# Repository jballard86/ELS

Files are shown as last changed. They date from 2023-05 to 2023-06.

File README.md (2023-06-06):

# Electronic Lead Screw
    By Jeff Ballard

Anticipated features:
  - Metric / Inch threading
  - Metric / Inch feeding
  - Auto threading with 2 steppers
  - Auto turn to a specified diameter
  - Pendent Control with:
    - Manual Z control
    - Manual X control
  - Radius cutting
  - Ball cutting
  - chamfer cutting
  - Digital Dial replacements (pipe dream)

This Lead Screw is 100% untested at this point, the code works on a test stand that has the following:
  - 24v power supply
  - 12v power supply
  - Custom PCB w/ a Teensy 4.0
  - 1 stepper motor w/Driver
  - 1 DC motor w/encoder
  - various display/interface hardware

PCB is 100% operational on test board.  Cad files to come for mounting all components in a housing for mounting near the lathe.

Lathe installation will happen shortly.

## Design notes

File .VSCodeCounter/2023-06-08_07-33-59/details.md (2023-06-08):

# Details

Date : 2023-06-08 07:33:59

Directory f:\\OneDrive\\Documents\\PlatformIO\\Projects\\ELS\\src

Total : 10 files,  1261 codes, 176 comments, 125 blanks, all 1562 lines

[Summary](results.md) / Details / [Diff Summary](diff.md) / [Diff Details](diff-details.md)

## Files
| filename | language | code | comment | blank | total |
| :--- | :--- | ---: | ---: | ---: | ---: |
| [src/Auto_Radius.h](/src/Auto_Radius.h) | C++ | 104 | 40 | 16 | 160 |
| [src/Chamfer.h](/src/Chamfer.h) | C++ | 2 | 0 | 1 | 3 |
| [src/Display.h](/src/Display.h) | C++ | 82 | 5 | 21 | 108 |
| [src/Feed.h](/src/Feed.h) | C++ | 17 | 1 | 7 | 25 |
| [src/Interface.h](/src/Interface.h) | C++ | 584 | 44 | 24 | 652 |
| [src/Interrupts.h](/src/Interrupts.h) | C++ | 21 | 3 | 7 | 31 |
| [src/Main.cpp](/src/Main.cpp) | C++ | 71 | 28 | 15 | 114 |
| [src/Menu.h](/src/Menu.h) | C++ | 351 | 12 | 24 | 387 |
| [src/Things_to_do.h](/src/Things_to_do.h) | C++ | 0 | 24 | 1 | 25 |
| [src/Thread.h](/src/Thread.h) | C++ | 29 | 19 | 9 | 57 |

[Summary](results.md) / Details / [Diff Summary](diff.md) / [Diff Details](diff-details.md)

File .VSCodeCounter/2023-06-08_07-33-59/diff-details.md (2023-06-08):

# Diff Details

Date : 2023-06-08 07:33:59

Directory f:\\OneDrive\\Documents\\PlatformIO\\Projects\\ELS\\src

Total : 6 files,  -13 codes, 17 comments, -3 blanks, all 1 lines

[Summary](results.md) / [Details](details.md) / [Diff Summary](diff.md) / Diff Details

## Files
| filename | language | code | comment | blank | total |
| :--- | :--- | ---: | ---: | ---: | ---: |
| [src/Auto_Radius.h](/src/Auto_Radius.h) | C++ | -4 | 11 | -1 | 6 |
| [src/Display.h](/src/Display.h) | C++ | 0 | 3 | 0 | 3 |
| [src/Feed.h](/src/Feed.h) | C++ | -4 | 0 | 0 | -4 |
| [src/Main.cpp](/src/Main.cpp) | C++ | -2 | 2 | -3 | -3 |
| [src/Things_to_do.h](/src/Things_to_do.h) | C++ | 0 | 1 | 0 | 1 |
| [src/Thread.h](/src/Thread.h) | C++ | -3 | 0 | 1 | -2 |

[Summary](results.md) / [Details](details.md) / [Diff Summary](diff.md) / Diff Details

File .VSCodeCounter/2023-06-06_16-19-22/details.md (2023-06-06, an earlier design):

# Details

Date : 2023-06-06 16:19:22

Directory f:\\OneDrive\\Documents\\PlatformIO\\Projects\\ELS\\src

Total : 9 files,  1148 codes, 146 comments, 116 blanks, all 1410 lines

[Summary](results.md) / Details / [Diff Summary](diff.md) / [Diff Details](diff-details.md)

## Files
| filename | language | code | comment | blank | total |
| :--- | :--- | ---: | ---: | ---: | ---: |
| [src/Auto_Radius.h](/src/Auto_Radius.h) | C++ | 21 | 27 | 8 | 56 |
| [src/Display.h](/src/Display.h) | C++ | 82 | 2 | 21 | 105 |
| [src/Feed.h](/src/Feed.h) | C++ | 21 | 1 | 7 | 29 |
| [src/Interface.h](/src/Interface.h) | C++ | 554 | 43 | 23 | 620 |
| [src/Interrupts.h](/src/Interrupts.h) | C++ | 21 | 3 | 7 | 31 |
| [src/Main.cpp](/src/Main.cpp) | C++ | 69 | 19 | 18 | 106 |
| [src/Menu.h](/src/Menu.h) | C++ | 348 | 14 | 23 | 385 |
| [src/Things_to_do.h](/src/Things_to_do.h) | C++ | 0 | 18 | 1 | 19 |
| [src/Thread.h](/src/Thread.h) | C++ | 32 | 19 | 8 | 59 |

[Summary](results.md) / Details / [Diff Summary](diff.md) / [Diff Details](diff-details.md)

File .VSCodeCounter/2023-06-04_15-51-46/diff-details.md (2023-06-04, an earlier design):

# Diff Details

Date : 2023-06-04 15:51:46

Directory f:\\OneDrive\\Documents\\PlatformIO\\Projects\\ELS\\src

Total : 6 files,  13 codes, 5 comments, -3 blanks, all 15 lines

[Summary](results.md) / [Details](details.md) / [Diff Summary](diff.md) / Diff Details

## Files
| filename | language | code | comment | blank | total |
| :--- | :--- | ---: | ---: | ---: | ---: |
| [src/Display.h](/src/Display.h) | C++ | 6 | 1 | 4 | 11 |
| [src/Feed.h](/src/Feed.h) | C++ | 1 | -1 | -2 | -2 |
| [src/Interface.h](/src/Interface.h) | C++ | 4 | 0 | -1 | 3 |
| [src/Main.cpp](/src/Main.cpp) | C++ | 1 | 4 | -3 | 2 |
| [src/Things_to_do.h](/src/Things_to_do.h) | C++ | 0 | 3 | 0 | 3 |
| [src/Thread.h](/src/Thread.h) | C++ | 1 | -2 | -1 | -2 |

[Summary](results.md) / [Details](details.md) / [Diff Summary](diff.md) / Diff Details

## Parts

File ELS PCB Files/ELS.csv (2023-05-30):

# | Reference | Qty | Value | Footprint | DNP
1 | C1 | 1 | CL31B106KBHNNNE | ELS:CAPC3216X140N
2 | C2 | 1 | CL32B226MOJNNNECAP_CL32_SAM-M | ELS:CAP_CL32_SAM-M
3 | ENCODER0, POWER_INPUT0, STEPPER1, STEPPER2 | 4 | 1-2834015-4 | ELS:TE_1-2834015-4
4 | J1, J2, J3, J4, J5 | 5 | B4B-PH-K-S_LF__SN_ | SamacSys_Parts:SHDR4W50P0X200_1X4_990X450X600P
5 | PS1 | 1 | P78E05-1000 | ELS:CONV_P78E05-1000
6 | Q1, Q2, Q3, Q4, Q5, Q6 | 6 | MMBT2222ALT3G | SamacSys_Parts:SOT96P237X111-3N
7 | R1, R6, R9, R12, R15, R18 | 6 | CRCW12061K00FKEAC | ELS:RESC3216X60N
8 | R2, R7, R10, R13, R16, R19 | 6 | CR1206-FX-8250ELF | ELS:RESC3216X75N
9 | R5, R8, R11, R14, R17, R20 | 6 | CRCW1206220RFKEAC | ELS:RESC3216X60N
10 | R23, R24, R25, R26 | 4 | CRCW12064K70FKEBC | SamacSys_Parts:RESC3216X60N
11 | TEENSY_4.0 | 1 | TEENSY_4.0 | ELS:TEENSY_4.0

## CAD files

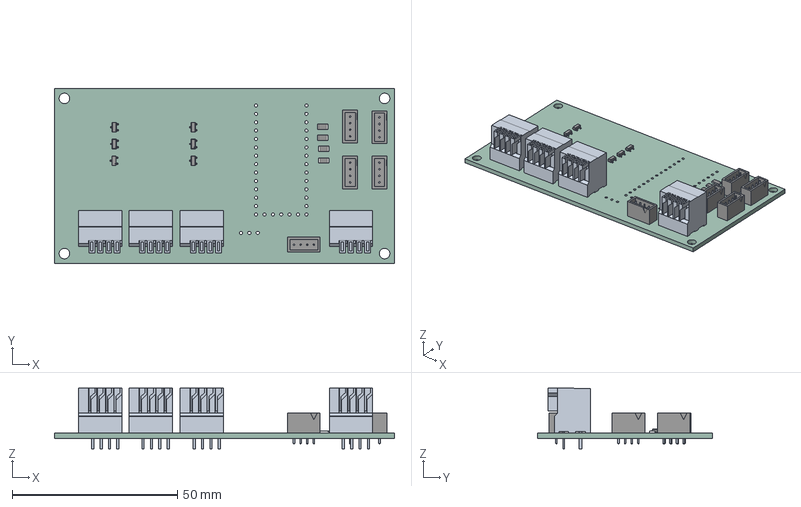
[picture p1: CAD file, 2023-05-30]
ELS PCB Files/ELS.step
103.0 x 53.0 x 18.5 mm
ELS PCB

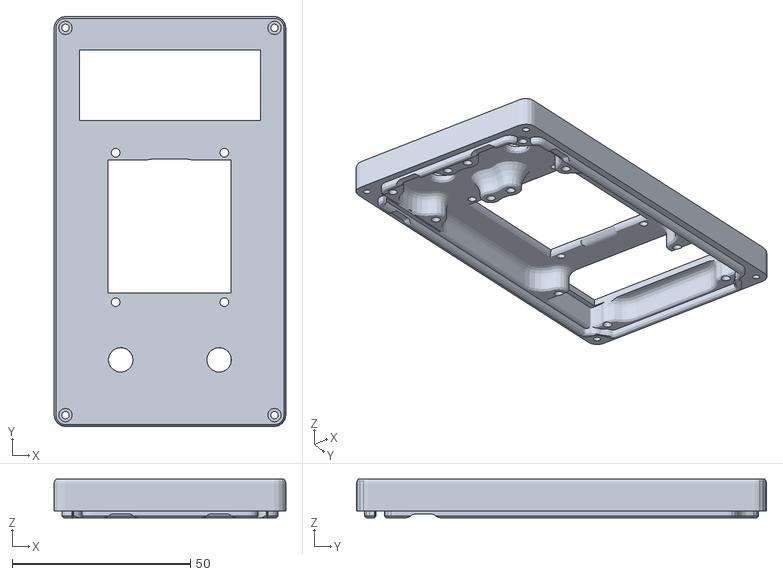
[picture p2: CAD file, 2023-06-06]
ELS STL Files/Housing Top r3.stl
65.0 x 115.0 x 10.9

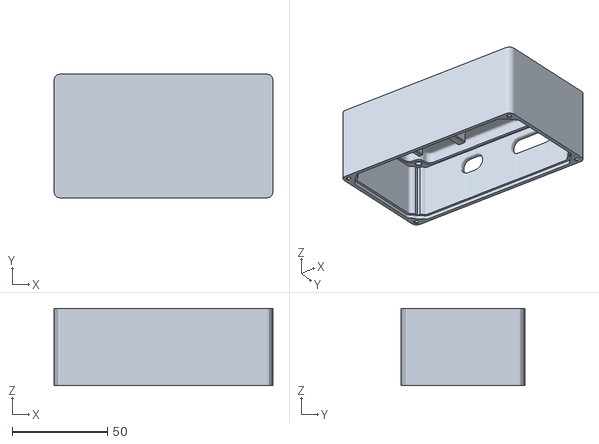
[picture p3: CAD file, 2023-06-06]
ELS STL Files/Housing Bottom r2.stl
115.0 x 65.0 x 40.6

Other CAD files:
ELS PCB Files/1-2834015-4.iam
ELS PCB Files/B4B-PH-K-S_LF__SN_.iam
ELS PCB Files/COMPOUND.ipt
ELS PCB Files/COMPOUND_1.ipt
ELS PCB Files/CRCW12064K70FKEBC.iam
ELS PCB Files/ELS PCB.ipt
ELS PCB Files/MMBT2222ALT3G.iam
ELS PCB Files/SOLID.ipt
ELS PCB Files/SOLID_1.ipt

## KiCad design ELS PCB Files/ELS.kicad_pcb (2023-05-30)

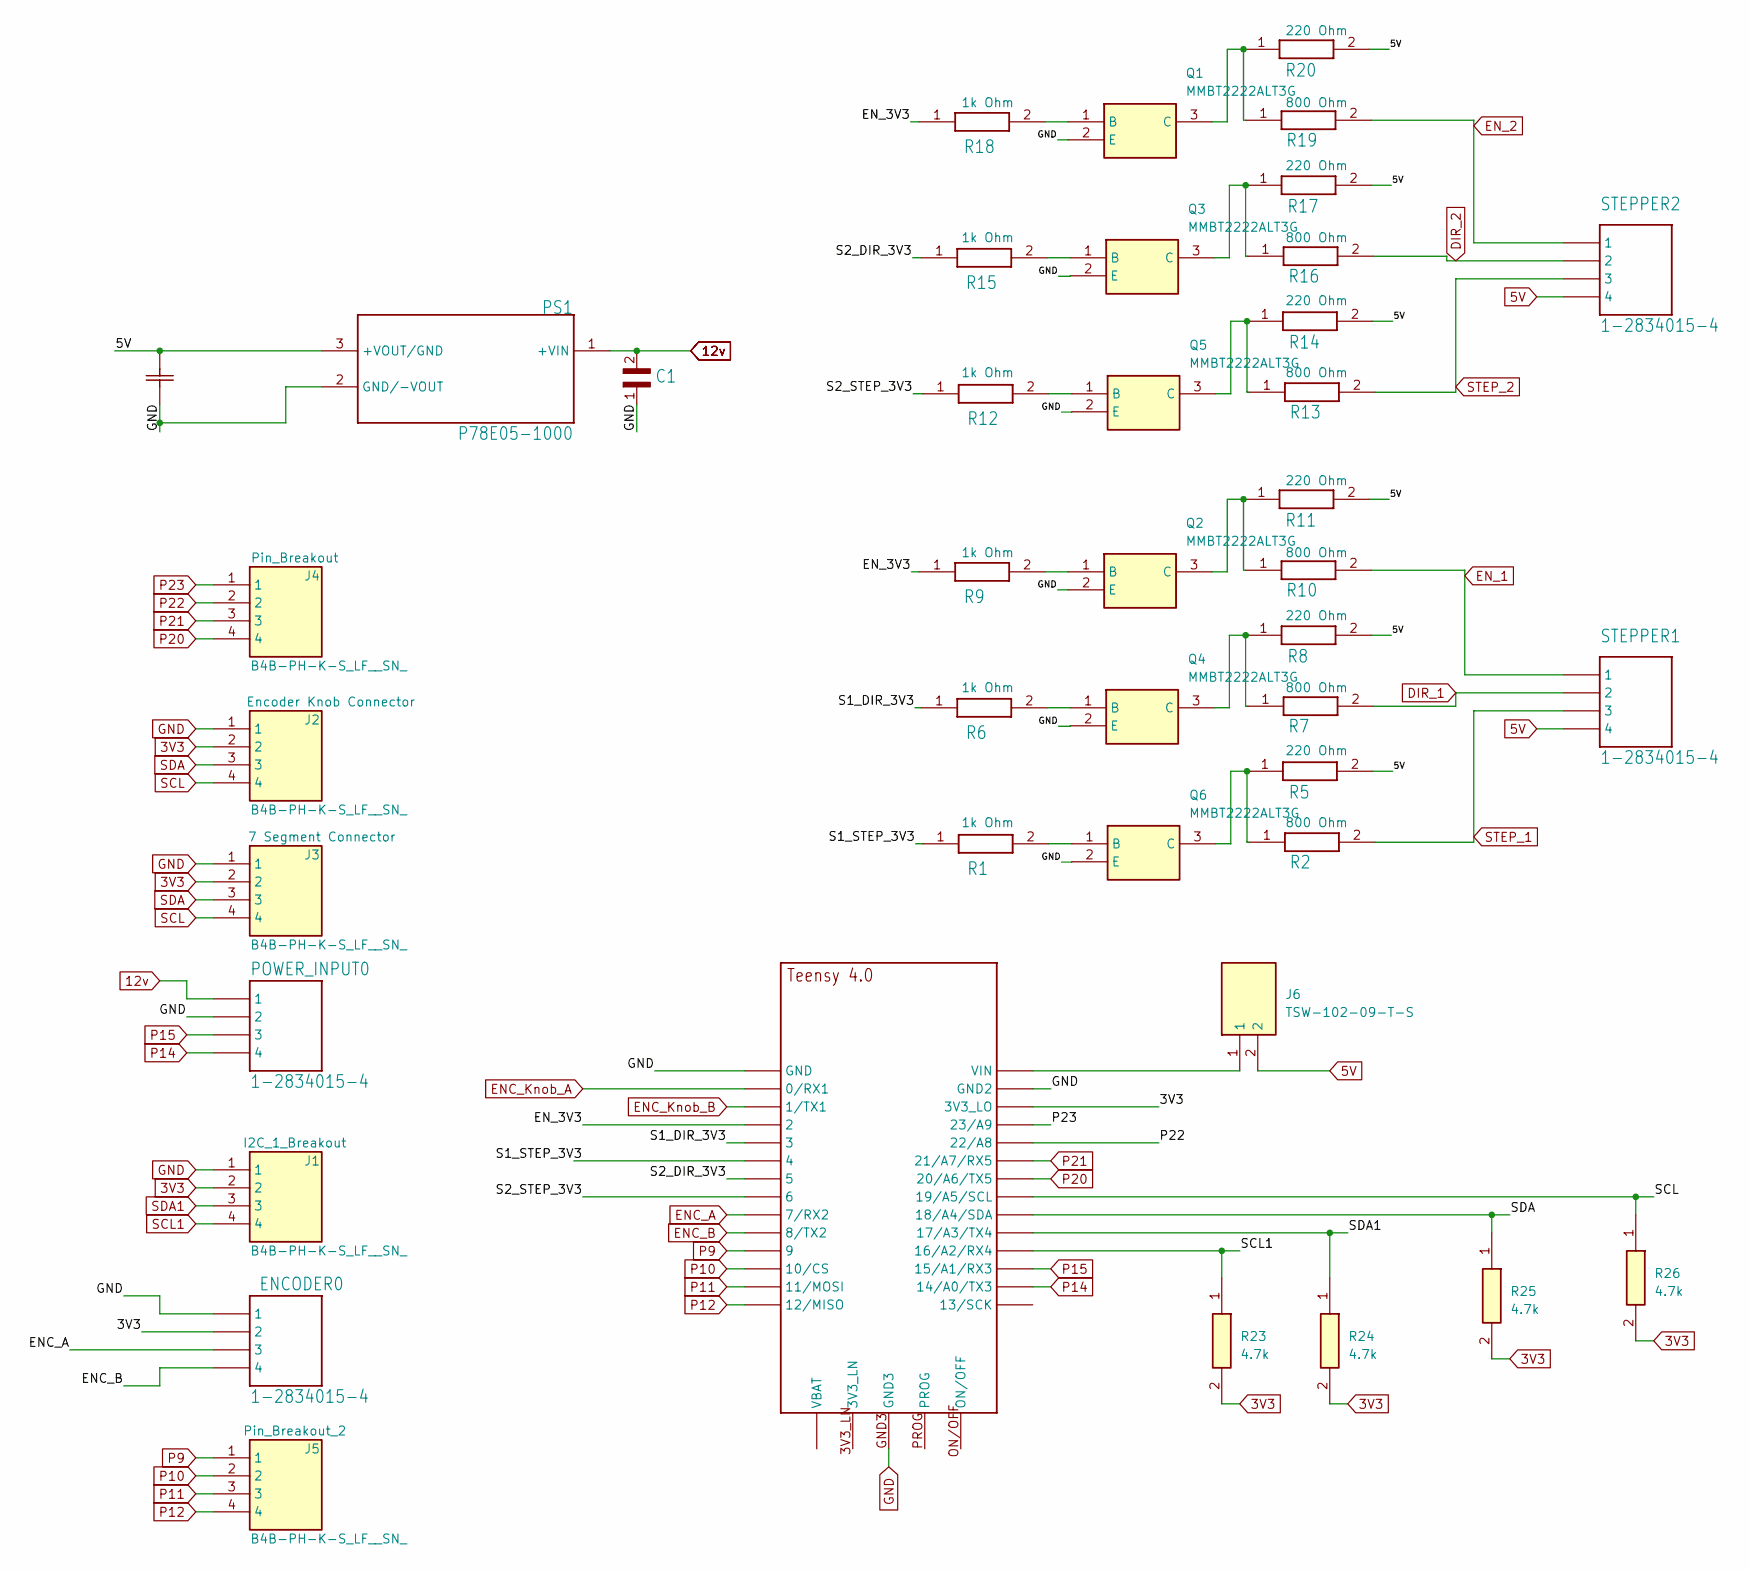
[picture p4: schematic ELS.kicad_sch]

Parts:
C1: CL31B106KBHNNNE; CAPC3216X140N
C2: CL32B226MOJNNNECAP_CL32_SAM-M; CAP_CL32_SAM-M
ENCODER0: 1-2834015-4; TE_1-2834015-4
J1, J2, J3, J4, J5: B4B-PH-K-S_LF__SN_; SHDR4W50P0X200_1X4_990X450X600P; Manufacturer_Part_Number B4B-PH-K-S(LF)(SN)
J6: TSW-102-09-T-S; TSW-102-XX-YY-S; Manufacturer_Part_Number TSW-102-09-T-S
POWER_INPUT0: 1-2834015-4; TE_1-2834015-4
PS1: P78E05-1000; CONV_P78E05-1000; VOLTAGE 5v
Q1, Q2, Q3, Q4, Q5, Q6: MMBT2222ALT3G; SOT96P237X111-3N; Mouser Part Number 863-MMBT2222ALT3G
R1, R6, R9, R12, R15, R18: CRCW12061K00FKEAC; RESC3216X60N
R2, R7, R10, R13, R16, R19: CR1206-FX-8250ELF; RESC3216X75N
R5, R8, R11, R14, R17, R20: CRCW1206220RFKEAC; RESC3216X60N
R23, R24, R25, R26: CRCW12064K70FKEBC; RESC3216X60N; Mouser Part Number 71-CRCW12064K70FKEBC
STEPPER1, STEPPER2: 1-2834015-4; TE_1-2834015-4
TEENSY_4.0: TEENSY_4.0

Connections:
3V3: ENCODER0.2_1 (2), ENCODER0.2_2 (2), J1.2, J2.2, J3.2, R23.2, R24.2, R25.2, R26.2, TEENSY_4.0.3V3_LO
5V: C2.2, J6.2, PS1.3 (+VOUT/GND), R5.2, R8.2, R11.2, R14.2, R17.2, R20.2, STEPPER1.4_1 (4), STEPPER1.4_2 (4), STEPPER2.4_1 (4), STEPPER2.4_2 (4)
12v: C1.2, POWER_INPUT0.1_1 (1), POWER_INPUT0.1_2 (1), PS1.1 (+VIN)
/EN_3V3: R9.1, R18.1, TEENSY_4.0.2
/S1_DIR_3V3: R6.1, TEENSY_4.0.3/CANTX (3)
/S1_STEP_3V3: R1.1, TEENSY_4.0.4/CANRX (4)
/S2_DIR_3V3: R15.1, TEENSY_4.0.5
/S2_STEP_3V3: R12.1, TEENSY_4.0.6
DIR_1: R7.2, STEPPER1.2_1 (2), STEPPER1.2_2 (2)
DIR_2: R16.2, STEPPER2.2_1 (2), STEPPER2.2_2 (2)
ENC_A: ENCODER0.3_1 (3), ENCODER0.3_2 (3), TEENSY_4.0.7 (7/RX2)
ENC_B: ENCODER0.4_1 (4), ENCODER0.4_2 (4), TEENSY_4.0.8 (8/TX2)
ENC_Knob_A: TEENSY_4.0.0/RX (0/RX1)
ENC_Knob_B: TEENSY_4.0.1/TX (1/TX1)
EN_1: R10.2, STEPPER1.1_1 (1), STEPPER1.1_2 (1)
EN_2: R19.2, STEPPER2.1_1 (1), STEPPER2.1_2 (1)
GND: C1.1, C2.1, ENCODER0.1_1 (1), ENCODER0.1_2 (1), J1.1, J2.1, J3.1, POWER_INPUT0.2_1 (2), POWER_INPUT0.2_2 (2), PS1.2 (GND/-VOUT), Q1.2 (E), Q2.2 (E), Q3.2 (E), Q4.2 (E), Q5.2 (E), Q6.2 (E), TEENSY_4.0.GND, TEENSY_4.0.GND2, TEENSY_4.0.GND3
unnamed: J6.1, TEENSY_4.0.VIN
unnamed: Q1.1 (B), R18.2
unnamed: Q1.3 (C), R19.1, R20.1
unnamed: Q2.1 (B), R9.2
unnamed: Q2.3 (C), R10.1, R11.1
unnamed: Q3.1 (B), R15.2
unnamed: Q3.3 (C), R16.1, R17.1
unnamed: Q4.1 (B), R6.2
unnamed: Q4.3 (C), R7.1, R8.1
unnamed: Q5.1 (B), R12.2
unnamed: Q5.3 (C), R13.1, R14.1
unnamed: Q6.1 (B), R1.2
unnamed: Q6.3 (C), R2.1, R5.1
P9: J5.1, TEENSY_4.0.9/CS (9)
P10: J5.2, TEENSY_4.0.10/CS
P11: J5.3, TEENSY_4.0.11/MOSI
P12: J5.4, TEENSY_4.0.12/MISO
P14: POWER_INPUT0.4_1 (4), POWER_INPUT0.4_2 (4), TEENSY_4.0.14/A0 (14/A0/TX3)
P15: POWER_INPUT0.3_1 (3), POWER_INPUT0.3_2 (3), TEENSY_4.0.15/A1 (15/A1/RX3)
P20: J4.4, TEENSY_4.0.20/A6 (20/A6/TX5)
P21: J4.3, TEENSY_4.0.21/A7 (21/A7/RX5)
P22: J4.2, TEENSY_4.0.22/A8
P23: J4.1, TEENSY_4.0.23/A9
SCL: J2.4, J3.4, R26.1, TEENSY_4.0.19/A5/SCL
SCL1: J1.4, R23.1, TEENSY_4.0.16/A2 (16/A2/RX4)
SDA: J2.3, J3.3, R25.1, TEENSY_4.0.18/A4/SDA
SDA1: J1.3, R24.1, TEENSY_4.0.17/A3 (17/A3/TX4)
STEP_1: R2.2, STEPPER1.3_1 (3), STEPPER1.3_2 (3)
STEP_2: R13.2, STEPPER2.3_1 (3), STEPPER2.3_2 (3)

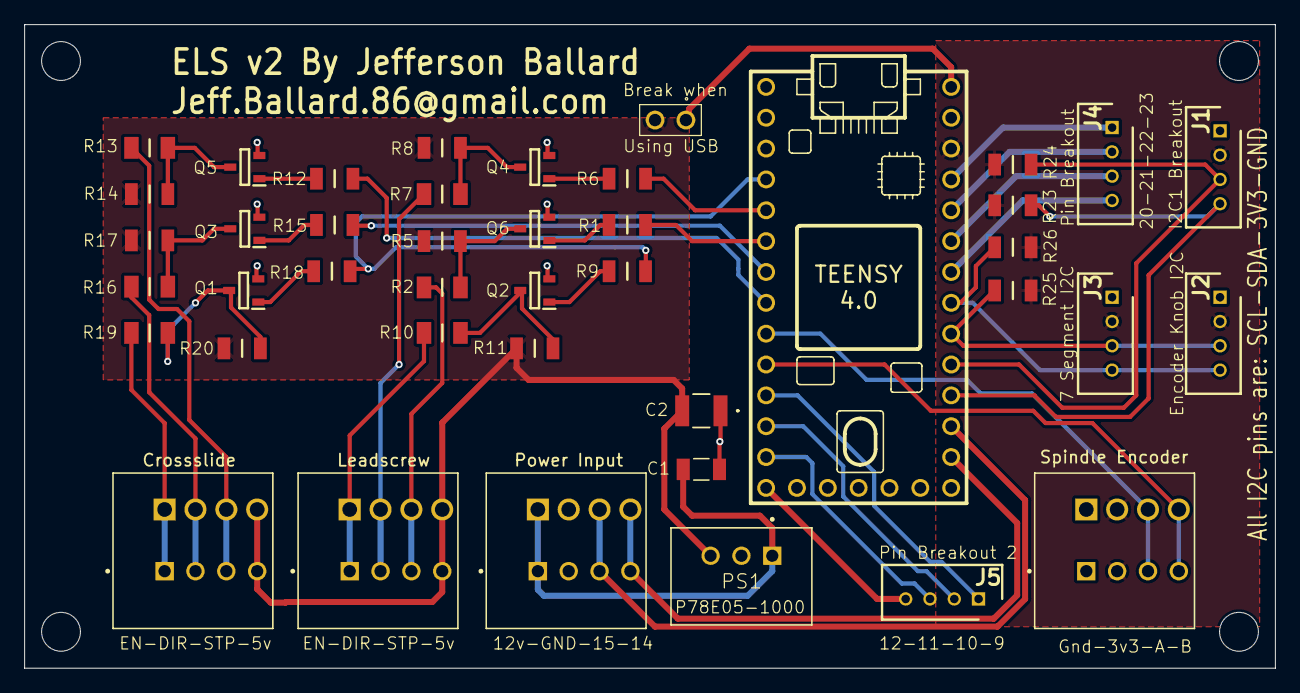
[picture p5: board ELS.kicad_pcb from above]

Board: 2 copper layers, 103.0 x 53.0 mm, 42 parts (0 on the bottom side), 44 nets.

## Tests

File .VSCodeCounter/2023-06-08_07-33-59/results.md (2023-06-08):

# Summary

Date : 2023-06-08 07:33:59

Directory f:\\OneDrive\\Documents\\PlatformIO\\Projects\\ELS\\src

Total : 10 files,  1261 codes, 176 comments, 125 blanks, all 1562 lines

Summary / [Details](details.md) / [Diff Summary](diff.md) / [Diff Details](diff-details.md)

## Languages
| language | files | code | comment | blank | total |
| :--- | ---: | ---: | ---: | ---: | ---: |
| C++ | 10 | 1,261 | 176 | 125 | 1,562 |

## Directories
| path | files | code | comment | blank | total |
| :--- | ---: | ---: | ---: | ---: | ---: |
| . | 10 | 1,261 | 176 | 125 | 1,562 |

Summary / [Details](details.md) / [Diff Summary](diff.md) / [Diff Details](diff-details.md)

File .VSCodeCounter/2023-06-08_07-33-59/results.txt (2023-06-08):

Date : 2023-06-08 07:33:59
Directory : f:\OneDrive\Documents\PlatformIO\Projects\ELS\src
Total : 10 files,  1261 codes, 176 comments, 125 blanks, all 1562 lines

Languages
+----------+------------+------------+------------+------------+------------+
| language | files      | code       | comment    | blank      | total      |
+----------+------------+------------+------------+------------+------------+
| C++      |         10 |      1,261 |        176 |        125 |      1,562 |
+----------+------------+------------+------------+------------+------------+

Directories
+------------------------------------------------------------------+------------+------------+------------+------------+------------+
| path                                                             | files      | code       | comment    | blank      | total      |
+------------------------------------------------------------------+------------+------------+------------+------------+------------+
| .                                                                |         10 |      1,261 |        176 |        125 |      1,562 |
+------------------------------------------------------------------+------------+------------+------------+------------+------------+

Files
+------------------------------------------------------------------+----------+------------+------------+------------+------------+
| filename                                                         | language | code       | comment    | blank      | total      |
+------------------------------------------------------------------+----------+------------+------------+------------+------------+
| f:\OneDrive\Documents\PlatformIO\Projects\ELS\src\Auto_Radius.h  | C++      |        104 |         40 |         16 |        160 |
| f:\OneDrive\Documents\PlatformIO\Projects\ELS\src\Chamfer.h      | C++      |          2 |          0 |          1 |          3 |
| f:\OneDrive\Documents\PlatformIO\Projects\ELS\src\Display.h      | C++      |         82 |          5 |         21 |        108 |
| f:\OneDrive\Documents\PlatformIO\Projects\ELS\src\Feed.h         | C++      |         17 |          1 |          7 |         25 |
| f:\OneDrive\Documents\PlatformIO\Projects\ELS\src\Interface.h    | C++      |        584 |         44 |         24 |        652 |
| f:\OneDrive\Documents\PlatformIO\Projects\ELS\src\Interrupts.h   | C++      |         21 |          3 |          7 |         31 |
| f:\OneDrive\Documents\PlatformIO\Projects\ELS\src\Main.cpp       | C++      |         71 |         28 |         15 |        114 |
| f:\OneDrive\Documents\PlatformIO\Projects\ELS\src\Menu.h         | C++      |        351 |         12 |         24 |        387 |
| f:\OneDrive\Documents\PlatformIO\Projects\ELS\src\Things_to_do.h | C++      |          0 |         24 |          1 |         25 |
| f:\OneDrive\Documents\PlatformIO\Projects\ELS\src\Thread.h       | C++      |         29 |         19 |          9 |         57 |
| Total                                                            |          |      1,261 |        176 |        125 |      1,562 |
+------------------------------------------------------------------+----------+------------+------------+------------+------------+

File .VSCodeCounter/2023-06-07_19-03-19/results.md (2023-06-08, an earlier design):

# Summary

Date : 2023-06-07 19:03:19

Directory f:\\OneDrive\\Documents\\PlatformIO\\Projects\\ELS\\src

Total : 10 files,  1244 codes, 154 comments, 127 blanks, all 1525 lines

Summary / [Details](details.md) / [Diff Summary](diff.md) / [Diff Details](diff-details.md)

## Languages
| language | files | code | comment | blank | total |
| :--- | ---: | ---: | ---: | ---: | ---: |
| C++ | 10 | 1,244 | 154 | 127 | 1,525 |

## Directories
| path | files | code | comment | blank | total |
| :--- | ---: | ---: | ---: | ---: | ---: |
| . | 10 | 1,244 | 154 | 127 | 1,525 |

Summary / [Details](details.md) / [Diff Summary](diff.md) / [Diff Details](diff-details.md)

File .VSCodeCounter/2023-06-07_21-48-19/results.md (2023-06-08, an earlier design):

# Summary

Date : 2023-06-07 21:48:19

Directory f:\\OneDrive\\Documents\\PlatformIO\\Projects\\ELS\\src

Total : 10 files,  1274 codes, 159 comments, 128 blanks, all 1561 lines

Summary / [Details](details.md) / [Diff Summary](diff.md) / [Diff Details](diff-details.md)

## Languages
| language | files | code | comment | blank | total |
| :--- | ---: | ---: | ---: | ---: | ---: |
| C++ | 10 | 1,274 | 159 | 128 | 1,561 |

## Directories
| path | files | code | comment | blank | total |
| :--- | ---: | ---: | ---: | ---: | ---: |
| . | 10 | 1,274 | 159 | 128 | 1,561 |

Summary / [Details](details.md) / [Diff Summary](diff.md) / [Diff Details](diff-details.md)

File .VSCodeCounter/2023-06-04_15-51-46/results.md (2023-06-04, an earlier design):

# Summary

Date : 2023-06-04 15:51:46

Directory f:\\OneDrive\\Documents\\PlatformIO\\Projects\\ELS\\src

Total : 9 files,  1127 codes, 130 comments, 106 blanks, all 1363 lines

Summary / [Details](details.md) / [Diff Summary](diff.md) / [Diff Details](diff-details.md)

## Languages
| language | files | code | comment | blank | total |
| :--- | ---: | ---: | ---: | ---: | ---: |
| C++ | 9 | 1,127 | 130 | 106 | 1,363 |

## Directories
| path | files | code | comment | blank | total |
| :--- | ---: | ---: | ---: | ---: | ---: |
| . | 9 | 1,127 | 130 | 106 | 1,363 |

Summary / [Details](details.md) / [Diff Summary](diff.md) / [Diff Details](diff-details.md)

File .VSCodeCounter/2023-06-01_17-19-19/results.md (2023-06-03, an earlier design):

# Summary

Date : 2023-06-01 17:19:19

Directory f:\\OneDrive\\Documents\\PlatformIO\\Projects\\ELS\\src

Total : 9 files,  930 codes, 148 comments, 97 blanks, all 1175 lines

Summary / [Details](details.md) / [Diff Summary](diff.md) / [Diff Details](diff-details.md)

## Languages
| language | files | code | comment | blank | total |
| :--- | ---: | ---: | ---: | ---: | ---: |
| C++ | 9 | 930 | 148 | 97 | 1,175 |

## Directories
| path | files | code | comment | blank | total |
| :--- | ---: | ---: | ---: | ---: | ---: |
| . | 9 | 930 | 148 | 97 | 1,175 |

Summary / [Details](details.md) / [Diff Summary](diff.md) / [Diff Details](diff-details.md)

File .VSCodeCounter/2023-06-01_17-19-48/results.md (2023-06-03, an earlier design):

# Summary

Date : 2023-06-01 17:19:48

Directory f:\\OneDrive\\Documents\\PlatformIO\\Projects\\ELS\\include

Total : 1 files,  139 codes, 18 comments, 14 blanks, all 171 lines

Summary / [Details](details.md) / [Diff Summary](diff.md) / [Diff Details](diff-details.md)

## Languages
| language | files | code | comment | blank | total |
| :--- | ---: | ---: | ---: | ---: | ---: |
| C++ | 1 | 139 | 18 | 14 | 171 |

## Directories
| path | files | code | comment | blank | total |
| :--- | ---: | ---: | ---: | ---: | ---: |
| . | 1 | 139 | 18 | 14 | 171 |

Summary / [Details](details.md) / [Diff Summary](diff.md) / [Diff Details](diff-details.md)

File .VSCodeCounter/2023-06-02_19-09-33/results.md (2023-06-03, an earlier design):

# Summary

Date : 2023-06-02 19:09:33

Directory f:\\OneDrive\\Documents\\PlatformIO\\Projects\\ELS\\src

Total : 9 files,  966 codes, 165 comments, 107 blanks, all 1238 lines

Summary / [Details](details.md) / [Diff Summary](diff.md) / [Diff Details](diff-details.md)

## Languages
| language | files | code | comment | blank | total |
| :--- | ---: | ---: | ---: | ---: | ---: |
| C++ | 9 | 966 | 165 | 107 | 1,238 |

## Directories
| path | files | code | comment | blank | total |
| :--- | ---: | ---: | ---: | ---: | ---: |
| . | 9 | 966 | 165 | 107 | 1,238 |

Summary / [Details](details.md) / [Diff Summary](diff.md) / [Diff Details](diff-details.md)

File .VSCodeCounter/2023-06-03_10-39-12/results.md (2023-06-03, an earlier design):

# Summary

Date : 2023-06-03 10:39:12

Directory f:\\OneDrive\\Documents\\PlatformIO\\Projects\\ELS\\src

Total : 9 files,  1114 codes, 125 comments, 109 blanks, all 1348 lines

Summary / [Details](details.md) / [Diff Summary](diff.md) / [Diff Details](diff-details.md)

## Languages
| language | files | code | comment | blank | total |
| :--- | ---: | ---: | ---: | ---: | ---: |
| C++ | 9 | 1,114 | 125 | 109 | 1,348 |

## Directories
| path | files | code | comment | blank | total |
| :--- | ---: | ---: | ---: | ---: | ---: |
| . | 9 | 1,114 | 125 | 109 | 1,348 |

Summary / [Details](details.md) / [Diff Summary](diff.md) / [Diff Details](diff-details.md)

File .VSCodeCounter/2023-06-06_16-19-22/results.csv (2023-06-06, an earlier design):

filename | "language" | "C++" | "comment" | "blank" | "total"
f:\OneDrive\Documents\PlatformIO\Projects\ELS\src\Auto_Radius.h | "C++" | 21 | 27 | 8 | 56
f:\OneDrive\Documents\PlatformIO\Projects\ELS\src\Display.h | "C++" | 82 | 2 | 21 | 105
f:\OneDrive\Documents\PlatformIO\Projects\ELS\src\Feed.h | "C++" | 21 | 1 | 7 | 29
f:\OneDrive\Documents\PlatformIO\Projects\ELS\src\Interface.h | "C++" | 554 | 43 | 23 | 620
f:\OneDrive\Documents\PlatformIO\Projects\ELS\src\Interrupts.h | "C++" | 21 | 3 | 7 | 31
f:\OneDrive\Documents\PlatformIO\Projects\ELS\src\Main.cpp | "C++" | 69 | 19 | 18 | 106
f:\OneDrive\Documents\PlatformIO\Projects\ELS\src\Menu.h | "C++" | 348 | 14 | 23 | 385
f:\OneDrive\Documents\PlatformIO\Projects\ELS\src\Things_to_do.h | "C++" | 0 | 18 | 1 | 19
f:\OneDrive\Documents\PlatformIO\Projects\ELS\src\Thread.h | "C++" | 32 | 19 | 8 | 59
Total | "-" | 1148 | 146 | 116 | 1410

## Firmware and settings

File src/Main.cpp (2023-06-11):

#include "Header.h"

//using: https://www.pjrc.com/teensy/td_timing_IntervalTimer.html

void setup() {
  Mode = Mode_Array_Pos;
  TPI = TPI_Array[TPI_Array_Pos];
  Pitch = Pitch_Array[Pitch_Array_Pos];
  Steps_Per_Thou = (LeadSPR * LeadScrew_TPI) / 1000;
  Steps_Per_hundredth_mm = 0.000393701 * LeadSPR * LeadScrew_TPI;   //0.000393701 is from the simplified equation: (LeadSPR/((1/LeadScrew_TPI)*25.4))/100

  spindle.setInitConfig();  //start spindle encoder
  spindle.init();

//----Stepper Setup----//
  //----Leadscrew----//
    LeadSpeed = MaxLeadRPM * LeadSPR / 60;         // Leadscrew Max Steps/sec
    LeadScrew.setMinPulseWidth(Step_Pulse_Width);
    LeadScrew.setMaxSpeed(LeadSpeed);
  //----Cross Slide----//
    Cross_Speed = MaxCrossRPM * CrossSPR / 60;         // CrossSlide Max Steps/sec
    CrossSlide.setMinPulseWidth(Step_Pulse_Width);
    CrossSlide.setMaxSpeed(Cross_Speed);
  //----MultiStepper Setup----//
    ZY_Steppers.addStepper(LeadScrew);
    ZY_Steppers.addStepper(CrossSlide);

//----Setup Various Display Methods----//
  Serial.begin(115200);             // starts serial
  Wire.begin();                     // starts I2C
    Wire.setSDA(SDA_Pin);           //setting up I2C Pins, if others are needed setup Wire1, Wire2, etc
    Wire.setSCL(SCL_Pin);   
  matrix.begin(0x70);               // starts 7 segment display, the () is the address
    matrix.setBrightness(15);       // sets 7 segment brightness to max, applicable values are 0-15
  Start_Feed_Display();             //runs display start routine
  Start_Graph_Display();
  delay(200);

//----Start I2C Encoder Interface----//
  Enc1.begin(0x36);
    Enc1.pinMode(Enc_Button, INPUT_PULLUP);  // Set Pin for encoder switch
    Enc1_Pos = Enc1.getEncoderPosition();     // get starting position
  Enc2.begin(0x37);
    Enc2_Pos = Enc2.getEncoderPosition();       
  Enc1.setEncoderPosition(Menu_pos);
  Enc1.setGPIOInterrupts(Enc_Button, 1);
  //Enc1.enableEncoderInterrupt();
  Enc2.setGPIOInterrupts(Enc_Button, 1);
  //Enc2.enableEncoderInterrupt();
 
//----Timer Setup----// 
  RPM_Check.begin(RPM_Calc, RPM_Check_INTERVAL_MS);       // Sets up an interrupt timer to run every "RPM_Check_INTERVAL_MS" (milli)
  Refresh_Rate_Timer.begin(Refresh, Refresh_Rate);        // Display Refresh Rate
  S_Timer.interval((124/60)*1000);
  S_Timer.reset();
}

void loop() {
  /* 
    -Display "Refresh()" is called every "Refresh_rate" milliseconds
      This allows interface, and menu to be ran
      Some functions inside of them are called on in special cases to update the display
    -Spindle Encoder is tracked using interrupts on the A/B pin changes
    -RPM_Calc runs on an interrupt timer in order to stay accurate with the RPM calculation
  */

//----Serial output for current debuging----//
  /*if (S_Timer.check() == 1) {Serial.print(CrossSlide.distanceToGo(),DEC); Serial.print("  "); Serial.print(LeadScrew.distanceToGo(),DEC);
    Serial.print("  "); Serial.println(LeadScrew.speed(),DEC);
  }*/

//----Feature/Mode Sub Routines----//             Proper Accelstepper run command for each feature
  if (Mode_Array_Pos == 0) {Feed();               LeadScrew.runSpeed();} 
  if (Mode_Array_Pos == 1) {Thread();             LeadScrew.runSpeed();} 
  if (Mode_Array_Pos == 2) {Auto_Thread();        ZY_Steppers.run();}
  if (Mode_Array_Pos == 3) {Turn_to_Diameter();   ZY_Steppers.run();}
  if (Mode_Array_Pos == 4) {Manual_Z();           LeadScrew.run();}
  if (Mode_Array_Pos == 5) {Manual_X();           CrossSlide.run();}
  if (Mode_Array_Pos == 6) {Auto_Radius();        ZY_Steppers.run();}
  if (Mode_Array_Pos == 7) {Chamfer();            ZY_Steppers.run();}
  //if (Mode_Array_Pos == 8) {Taper();              ZY_Steppers.run();}
  //if (Mode_Array_Pos == 9) {Knurling();           ZY_Steppers.run();}
  //if (Mode_Array_Pos == 10) {Test_Menu();         ZY_Steppers.run();}

}

/**
  @brief Calculates the total number of steps to get from A to B
  @param move_length  : length of move (in on mm)
*/
double Steps_per_Move(double move_length) {    
  double StepsPer;
  if (Metric == 0) {
    move_length = move_length / .001;
    StepsPer = move_length * Steps_Per_Thou;
  } 
  else {
    move_length = move_length / .01;
    StepsPer = move_length * Steps_Per_hundredth_mm;
  }
  return StepsPer;
}

/** @brief Adds up all remaining movement of the cross slide and lead screw.  Zero = no movement */
double ZY_Movement() {
  double remaining_distance = LeadScrew.distanceToGo() + CrossSlide.distanceToGo();
  return remaining_distance;
}

#include "Display.h"
#include "Feed.h"
#include "Interface.h"
#include "Interrupts.h"
#include "Menu.h"
#include "Thread.h"
#include <string>
#include "Auto_Radius.h"
#include "Chamfer.h"

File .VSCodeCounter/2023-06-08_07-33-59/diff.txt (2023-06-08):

Date : 2023-06-08 07:33:59
Directory : f:\OneDrive\Documents\PlatformIO\Projects\ELS\src
Total : 6 files,  -13 codes, 17 comments, -3 blanks, all 1 lines

Languages
+----------+------------+------------+------------+------------+------------+
| language | files      | code       | comment    | blank      | total      |
+----------+------------+------------+------------+------------+------------+
| C++      |          6 |        -13 |         17 |         -3 |          1 |
+----------+------------+------------+------------+------------+------------+

Directories
+------------------------------------------------------------------+------------+------------+------------+------------+------------+
| path                                                             | files      | code       | comment    | blank      | total      |
+------------------------------------------------------------------+------------+------------+------------+------------+------------+
| .                                                                |          6 |        -13 |         17 |         -3 |          1 |
+------------------------------------------------------------------+------------+------------+------------+------------+------------+

Files
+------------------------------------------------------------------+----------+------------+------------+------------+------------+
| filename                                                         | language | code       | comment    | blank      | total      |
+------------------------------------------------------------------+----------+------------+------------+------------+------------+
| f:\OneDrive\Documents\PlatformIO\Projects\ELS\src\Auto_Radius.h  | C++      |         -4 |         11 |         -1 |          6 |
| f:\OneDrive\Documents\PlatformIO\Projects\ELS\src\Display.h      | C++      |          0 |          3 |          0 |          3 |
| f:\OneDrive\Documents\PlatformIO\Projects\ELS\src\Feed.h         | C++      |         -4 |          0 |          0 |         -4 |
| f:\OneDrive\Documents\PlatformIO\Projects\ELS\src\Main.cpp       | C++      |         -2 |          2 |         -3 |         -3 |
| f:\OneDrive\Documents\PlatformIO\Projects\ELS\src\Things_to_do.h | C++      |          0 |          1 |          0 |          1 |
| f:\OneDrive\Documents\PlatformIO\Projects\ELS\src\Thread.h       | C++      |         -3 |          0 |          1 |         -2 |
| Total                                                            |          |        -13 |         17 |         -3 |          1 |
+------------------------------------------------------------------+----------+------------+------------+------------+------------+

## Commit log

2023-05-29 added auto thread menu, and thread depth calcs
2023-05-29 fixed thread depth calculations
    [Header.h, Thread.h]
2023-05-30 Auto Threading Submenu additions/tuning
2023-05-30 finished auto thread sub menu
2023-05-30 "finished" spindle angle code/math
2023-05-30 changed directory structure
    [1-2834015-4.iam, B4B-PH-K-S_LF__SN_.iam, COMPOUND.ipt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]
2023-06-01 Fixed Menu Bugs + Tweaks
    [Header.h, Main.cpp]
2023-06-01 Radius Sub Menu options added
    [diff.csv, diff.txt, results.csv]
2023-06-03 Added current 3d cad data
    [0603-NO.ipt, 0805-NO.ipt, 1-2834015-4.iam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]
2023-06-03 changed folder name
    [1-2834015-4.iam, B4B-PH-K-S_LF__SN_.iam, COMPOUND.ipt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]
2023-06-03 Replacced Continuous Stepper with Accelstepper
2023-06-04 Accelstepper and new PCB Update
2023-06-04 Cad Update
    Enclosure nearly complete
    [1-2834015-4.0001.iam, 1-2834015-4.iam, 4991 QT Rotary Encoder.0001.iam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]
2023-06-04 auto radius graphic update
    [diff.csv, diff.txt, results.csv]
2023-06-05 ELS Housing Files Complete
    [1-2834015-4.0002.iam, 1-2834015-4.iam, 4991 QT Rotary Encoder.0002.iam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]
2023-06-05 Enclosure tweaks
    [Electrronic Enclosure.0014.iam, Electrronic Enclosure.iam, Housing Bottom.0008.ipt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]
2023-06-05 fixed step rate, tweaked auto radius graphics
    [Header.h]
2023-06-06 removed parametric files
    only uploading STL files for enclosure, will likely add step files at a later date
    [0603-NO.ipt, 0805-NO.ipt, 1-2834015-4.0001.iam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]
2023-06-07 Lathe Coordinate correction
    changed coordinates from XY to ZY
    [Auto_Radius.h, Header.h]
2023-06-07 Fixed Cut_Pass
    The math in the Cut_Pass function was incorrect.
    Added support for all radius types.
    [Auto_Radius.h, Main.cpp]
2023-06-07 Build_XY_Array
    Finished the ZY array so that all points for all radius types are
    accurate for the finished radius.
    [Radius Plots.xlsx]
2023-06-08 Auto_Radius()
    Rough cut is ready to try on lathe.
    Final pass is not ready.
    Submenu for auto_radius() is not complete and has errors still.
    [Header.h]
2023-06-08 Tweaks - simplified the code in Feed.h and Thread.h added accelstepper run comands to each mode depending on needs added comments to functions
    [diff.csv, diff.txt, results.csv]
